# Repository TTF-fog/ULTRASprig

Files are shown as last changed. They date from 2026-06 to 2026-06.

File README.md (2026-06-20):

# the ULTRASprig

an updated version of the [Sprig](https://github.com/hackclub/sprig/), made to be ultra-modular and expansible!

# Why?
the current model of the sprig is a bit... outdated. It still runs on the RP2040, has only 4 (broken out) gpios and just 2Mb of flash. The ULTRASprig has 7 usable GPIOs, and a completely new expansion system that allows for up to 16MB of additional flash, + PSRAM. it also uses I2C "modules" to give even more  interfaces

## Notes:
- KiCad will throw a DRC error for the placement of the mounting headers (courtyard overlap with display), but this can be ignored safely 

# Setup
## RP2354B
- get the larger packages (the BQ, RP2354, and the TP) pre-assembled
- use a stencil to solder the smaller passives
- solder male headers into the broken out pins
## Mainboard
- Solder all components except the pinsockets
- while soldering the pinsockets, make sure to have 1mm of clearance between the tips and the SPI display
- insert the SD Card into the SPI Display
- for the battery headers, one battery header will be connected to the + and - of the battery, and the other should be connected to the battery pins of the coreboard
## Case
- the case must be printed in two parts, the front and the back
- there are 4 mounting holes in the case, which must be connected using screws to those mounting holes on the mainboard
- after that, place the backplate, ensuring that the battery pins line up with the battery hoels
# Usage
- build the firmware and flash it on the sprig

# Sub(Links)
- [Zine](Sprig_Zine.pdf)
- Mainboard
    - [Mainboard BoM](BOM.csv)
    - [Gerbers - Mainboard](gerbers.zip)
    - [Mainboard Design](Mainboard/)
- Core Board
    - [Core BoM](core_board/RP2354B/BOM.csv)
    - [Coreboard Design Files](core_board/RP2354B/)
- Expansions
    - IO Expander   
        - [Design](Expansions/IOExpander/)
        - [Gerbers](Expansions/IOExpander/Gerbers.zip)
        - [BoM](Expansions/IOExpander/BOM.csv)
    - Flash Breakout   
        - [Design](Expansions/FlashBreakout/)
        - [Gerbers](Expansions/FlashBreakout/gerbers.zip)
        - [BoM](Expansions/FlashBreakout/BOM.csv)
    - IMU Breakout   
        - [Design](Expansions/IMUBreakout/)
        - [Gerbers](Expansions/IMUBreakout/Gerbers.zip)
        - [BoM](Expansions/IMUBreakout/BOM.csv)

- [Gerbers - coreboard](core_board/RP2354B/Gerbers.zip)

# Zine
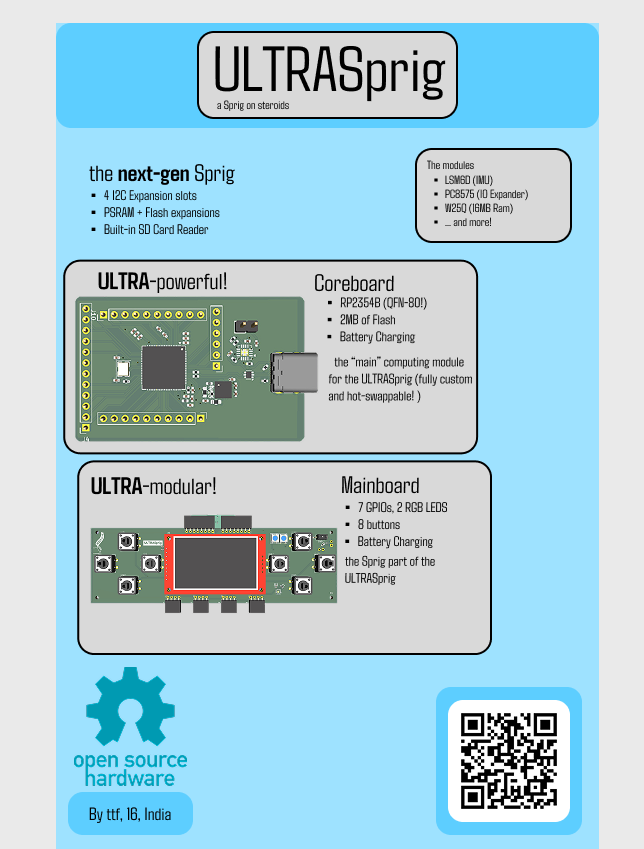
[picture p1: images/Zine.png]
Zine

> check the pdf version too!
# Renders
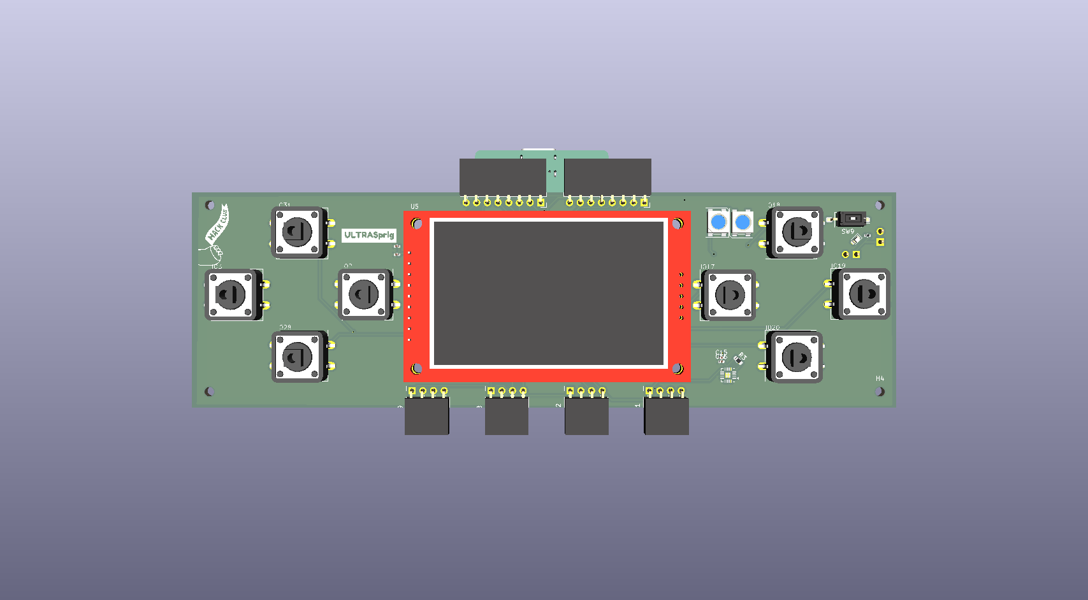
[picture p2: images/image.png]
front view

> front view

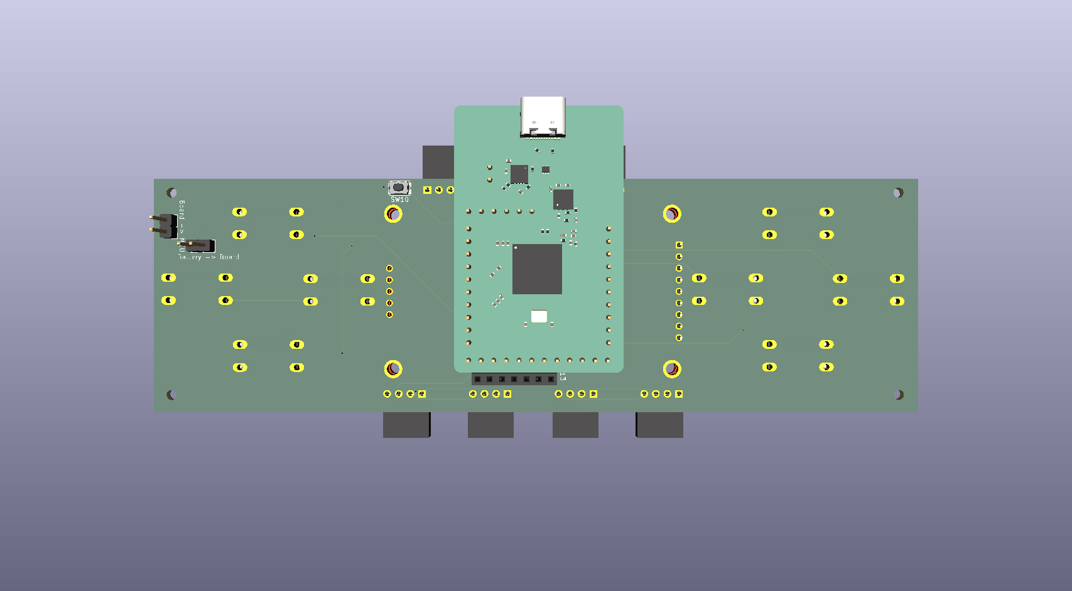
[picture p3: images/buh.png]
back view w/ board and battery headers

> back view w/ board and battery headers

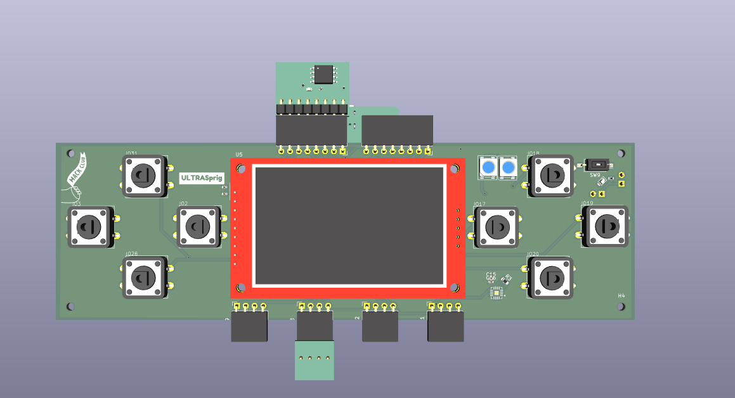
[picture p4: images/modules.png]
main board with modules

> front view, main board with modules

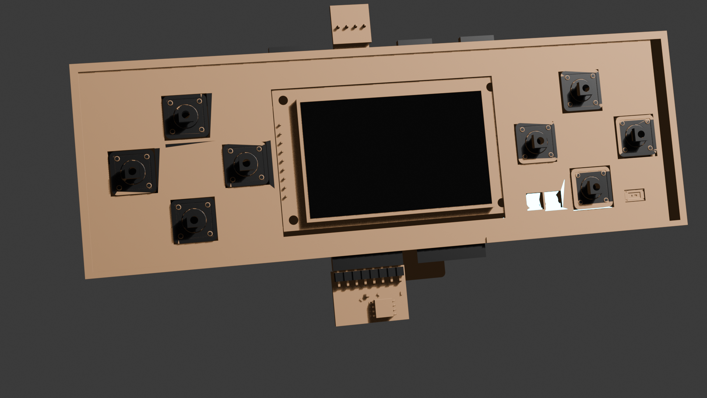
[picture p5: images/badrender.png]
horrible blender render

> a very rushed blender render rhyme

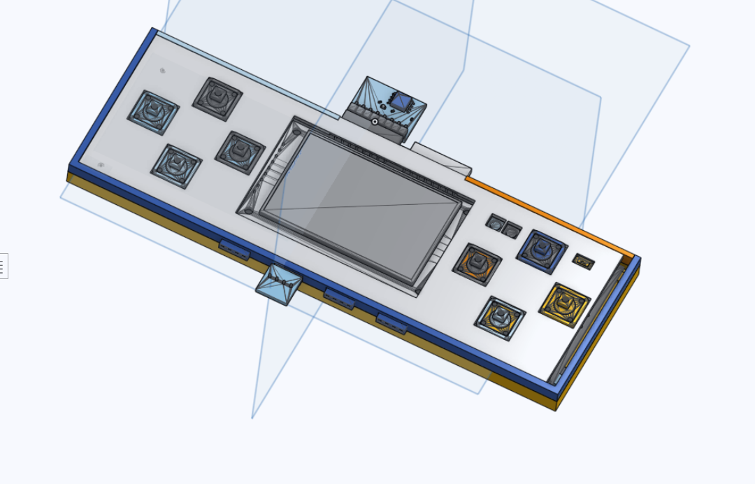
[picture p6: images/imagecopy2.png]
CAD

> case for the ULTRASprig

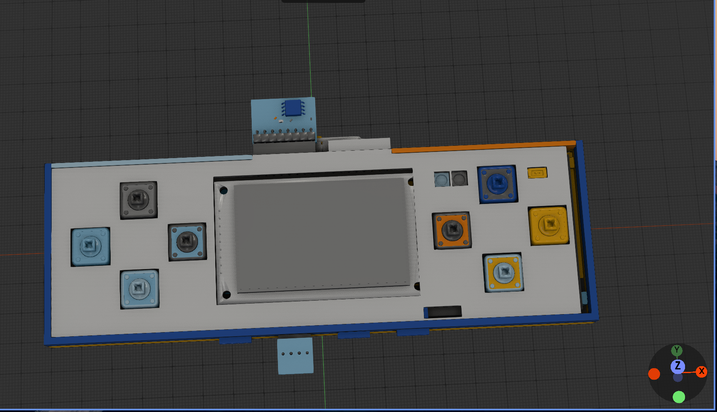
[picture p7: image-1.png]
the 13th reason

> textured preview of CAD
# Routing

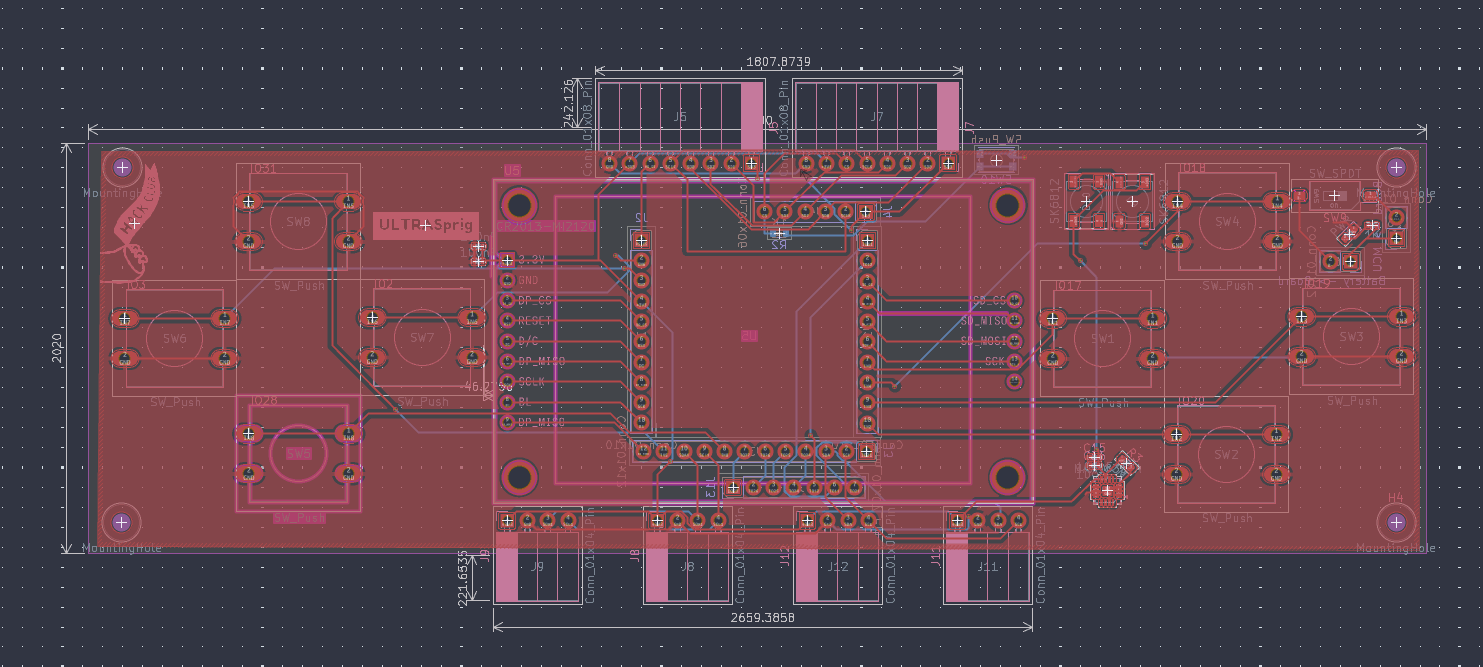
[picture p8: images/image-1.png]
routed mainboard

> routed mainboard

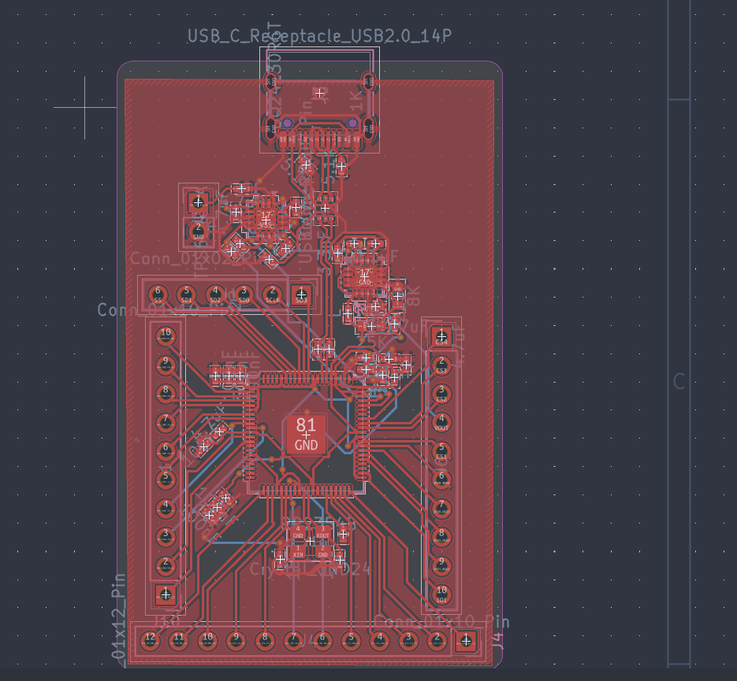
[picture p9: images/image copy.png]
routed coreboard

> routed coreboard

# Schematics
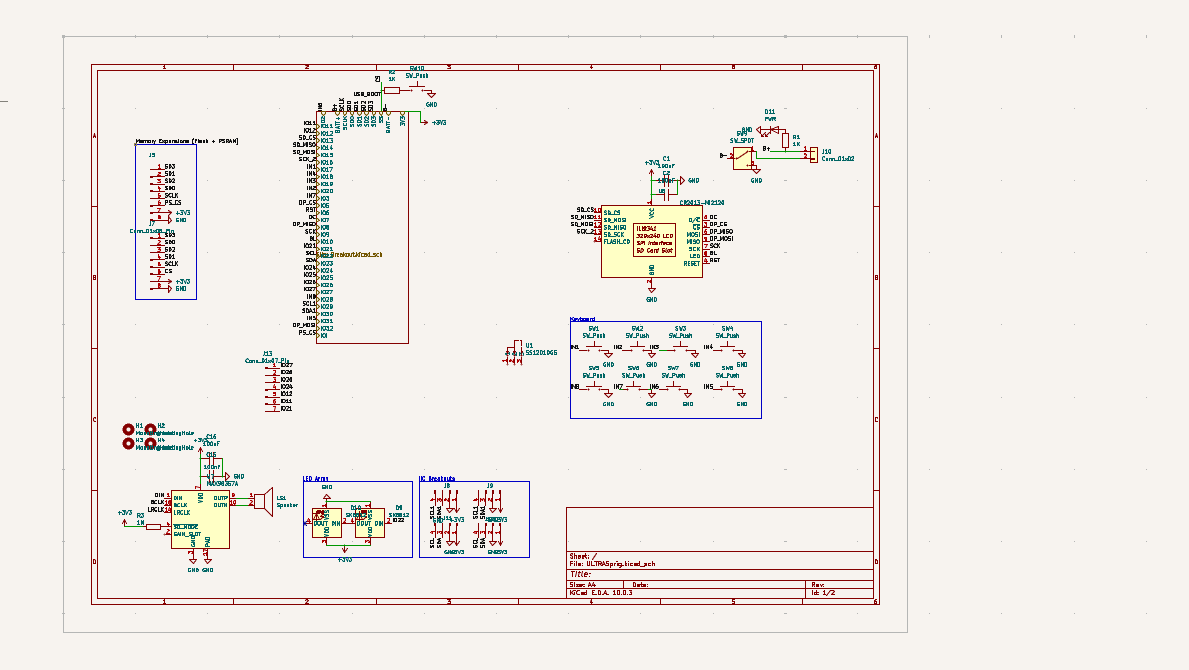
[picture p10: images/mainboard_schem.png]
mainboard schematic

> mainboard schematic

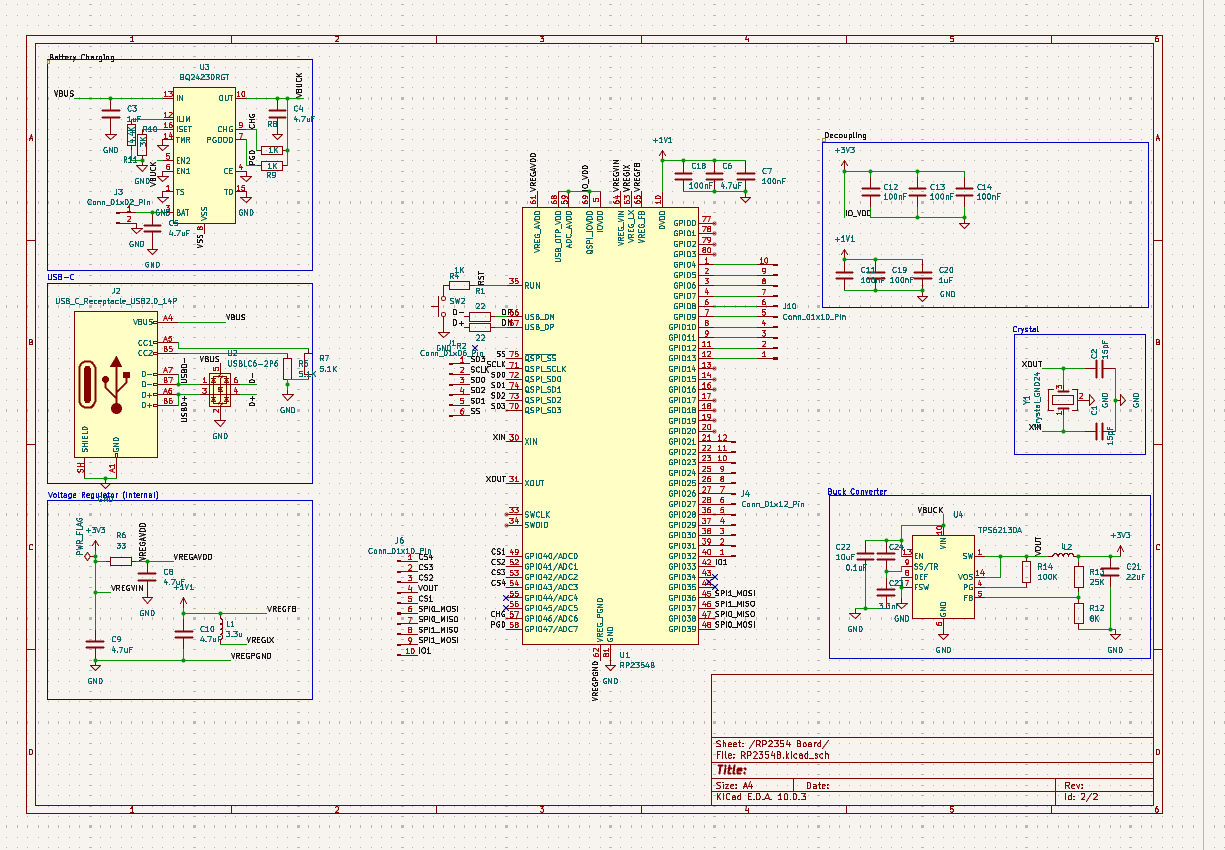
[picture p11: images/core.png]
core schematic

> coreboard schematic

> note: some of the cad model pictures are outdated, double-check the source file

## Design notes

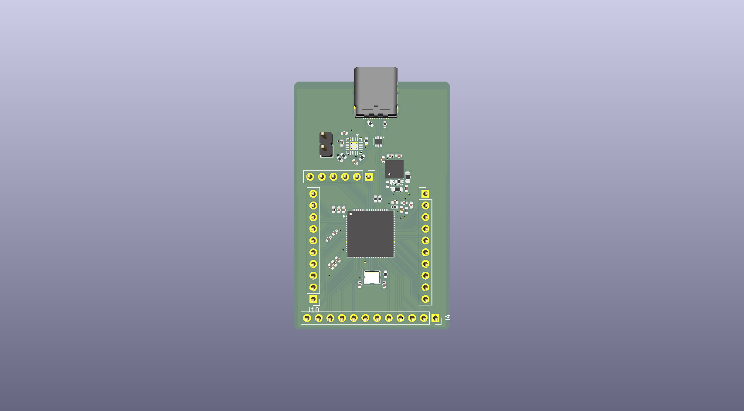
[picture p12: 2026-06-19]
core_board/RP2354B/buh.png

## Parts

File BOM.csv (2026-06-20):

Comment | Designator | Footprint | LCSC | Quantity | URL | Unit Price | Price
100nF | C1,C15,C16,C2 | C_0402_1005Metric | C1525 | 4 | https://www.lcsc.com/product-detail/C1525.html | 0.0031 | 0.31
1K | R1 | R_0402_1005Metric | C11702 | 1 | https://www.lcsc.com/product-detail/C11702.html | 0.0011 | 0.011
1K | R2 | R_0603_1608Metric | C21190 | 1 | https://www.lcsc.com/product-detail/C21190.html | 0.0017 | 0.017
1M | R3 | R_0603_1608Metric | C22935 | 1 | https://www.lcsc.com/product-detail/C22935.html | 0.0018 | 0.18
Conn_01x02 | J10,J6,J14 | PinHeader_1x02_P2.54mm_Vertical | C492401 | 3 | https://www.lcsc.com/product-detail/C492401.html | 0.0161 | 0.95
Conn_01x04_Pin | J11,J12,J8,J9 | PinSocket_1x04_P2.54mm_Horizontal | C2718488 | 4 | https://www.lcsc.com/product-detail/C2718488.html | 0.0786 | 0.79
Conn_01x06 | J4 | PinSocket_1x06_P2.54mm_Vertical | C7499363 | 1 | https://www.lcsc.com/product-detail/C7499363.html | 0.1286 | 0.64
Conn_01x07_Pin | J13 | PinSocket_1x07_P2.54mm_Vertical | C5371993 | 1 | https://www.lcsc.com/product-detail/C5371993.html | 0.0963 | 0.48
Conn_01x08_Pin | J5,J7 | PinSocket_1x08_P2.54mm_Horizontal | C7499328 | 2 | https://www.lcsc.com/product-detail/C7499328.html | 0.1351 | 0.68
Conn_01x10 | J1,J2 | PinSocket_1x10_P2.54mm_Vertical | C2925557 | 2 | https://www.lcsc.com/product-detail/C2925557.html | 0.1279 | 0.64
Conn_01x12 | J3 | PinSocket_1x12_P2.54mm_Vertical | C492401 | 1 | https://www.lcsc.com/product-detail/C492401.html | 0.0161 | 0.81
MAX98357A | U7 | TQFN-16-1EP_3x3mm_P0.5mm_EP1.23x1.23mm | C910544 | 1 | https://www.lcsc.com/product-detail/C910544.html | 1.3362 | 1.34
PWR | D11 | LED_0603_1608Metric | C2286 | 1 | https://www.lcsc.com/product-detail/C2286.html | 0.0073 | 0.73
SK6812 | D10,D9 | LED_SK6812_PLCC4_5.0x5.0mm_P3.2mm | C5378734 | 2 | https://www.lcsc.com/product-detail/C5378734.html | 0.1656 | 0.83
SW_Push | SW1,SW10,SW2,SW3,SW4,SW5,SW6,SW7,SW8 | SW_PUSH-12mm | C963201 | 9 | https://www.lcsc.com/product-detail/C963201.html | 0.216 | 1.08
SW_SPDT | SW9 | SW_SPST_B3S-1100 | C7421519 | 1 | https://www.lcsc.com/product-detail/C7421519.html | 0.444 | 0.44
CR2013-MI2120 | U5 | CR2013-MI2120 | N/A | 1 | https://robu.in/product/2-8-inch-lcm-tft-color-screen-ili9341v-with-spi-serial-port/ | 9.4 | 9.41
PCB Milling | N/A | N/A | N/A |  | https://jlcpcb.com | 7.7 | 7.7
 |  |  |  |  |  | 19.8755 | 27.038

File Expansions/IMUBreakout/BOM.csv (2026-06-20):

Comment | Designator | Footprint | LCSC | Quantity | Link | Unit Price | Total Price
100nF | C1 | C_0402_1005Metric | C1525 | 1 | https://www.lcsc.com/product-detail/C1525.html | 0.0031 | 0.31
1K | R1,R2 | R_0402_1005Metric | C11702 | 2 | https://www.lcsc.com/product-detail/C11702.html | 0.0011 | 0.11
Conn_01x04_Socket | J1 | PinHeader_1x04_P2.54mm_Horizontal | C194925 | 1 | https://www.lcsc.com/product-detail/C194925.html | 0.1205 | 0.6
LED | D1 | LED_0603_1608Metric | C2286 | 1 | https://www.lcsc.com/product-detail/C2286.html | 0.0073 | 0.73
LSM6DS3 | U1 | LGA-14_3x2.5mm_P0.5mm_LayoutBorder3x4y | C967633 | 1 | https://www.lcsc.com/product-detail/C967633.html | 1.576 | 1.58PCB
PCB Milling | N/A | N/A | N/A | 1 | https://jlcpcb.com | 2.2 | 2.2
 |  |  |  |  |  | 3.908 | 5.53

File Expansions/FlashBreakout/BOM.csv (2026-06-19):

Comment | Designator | Footprint | LCSC | Quantity | Link | Per Unit | Total
0 | R1 | R_0402_1005Metric | C17168 | 1 | https://lcsc.com/product-detail/C17168.html | 0.0011 | 0.11
100nF | C1 | C_0402_1005Metric | C1525 | 1 | https://lcsc.com/product-detail/C1525.html | 0.0031 | 0.31
1K | R2 | R_0402_1005Metric | C11702 | 1 | https://lcsc.com/product-detail/C11702.html | 0.0011 | 0.11
Conn_01x08_Pin | J1 | PinHeader_1x08_P2.54mm_Horizontal | C42431840 | 1 | https://lcsc.com/product-detail/C42431840.html | 0.1002 | 0.5
LED | D1 | LED_0603_1608Metric | C2286 | 1 | https://lcsc.com/product-detail/C2286.html | 0.0073 | 0.73
W25Q128JVS | U2 | SOIC-8_5.3x5.3mm_P1.27mm | C97521 | 1 | https://lcsc.com/product-detail/C97521.html | 2.4553 | 2.46
PCB | N/A | N/A | N/A | 1 | https://jlcpcb.com | 2.1 | 2.1
 |  |  |  |  |  | 4.6681 | 6.32

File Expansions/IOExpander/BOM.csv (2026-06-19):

Comment | Designator | Footprint | LCSC | Quantity | Link | Unit Price | Total Price
100nF | C1,C2 | C_0603_1608Metric | C14663 | 2 | https://www.lcsc.com/product-detail/C14663.html | 0.0172 | 1.72
Conn_01x04 | J1 | PinHeader_1x04_P2.54mm_Horizontal | C52016392 | 1 | https://www.lcsc.com/product-detail/C52016392.html | 0.0283 | 0.57
PCF8574AP | U1 | DIP-16_W7.62mm | C398072 | 1 | https://www.lcsc.com/product-detail/C398072.html | 0.79 | 0.79
Conn_01x08 | J2 | PinHeader_1x08_P2.54mm_Horizontal | C20607071 | 1 | https://www.lcsc.com/product-detail/C20607071.html | 0.0958 | 0.48
PCB Milling | n/a | n/a | n/a | 1 | https://jlcpcb.com | 2.2 | 2.2
 |  |  |  |  |  | 3.1313 | 5.76

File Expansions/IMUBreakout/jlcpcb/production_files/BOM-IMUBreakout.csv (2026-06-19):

Comment | Designator | Footprint | LCSC | Quantity
100nF | C1 | C_0402_1005Metric | C1525 | 1
1K | R1,R2 | R_0402_1005Metric | C11702 | 2
Conn_01x04_Socket | J1 | PinHeader_1x04_P2.54mm_Horizontal | C194925 | 1
LED | D1 | LED_0603_1608Metric | C2286 | 1
LSM6DS3 | U1 | LGA-14_3x2.5mm_P0.5mm_LayoutBorder3x4y | C967633 | 1

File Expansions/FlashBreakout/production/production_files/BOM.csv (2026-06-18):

Comment | Designator | Footprint | LCSC | Quantity
0 | R1 | R_0402_1005Metric | C17168 | 1
100nF | C1 | C_0402_1005Metric | C1525 | 1
1K | R2 | R_0402_1005Metric | C11702 | 1
Conn_01x08_Pin | J1 | PinHeader_1x08_P2.54mm_Horizontal | C42431840 | 1
LED | D1 | LED_0603_1608Metric | C2286 | 1
W25Q128JVS | U2 | SOIC-8_5.3x5.3mm_P1.27mm | C97521 | 1

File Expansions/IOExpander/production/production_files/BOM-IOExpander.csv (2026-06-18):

Comment | Designator | Footprint | LCSC | Quantity
100nF | C1,C2 | C_0603_1608Metric | C14663 | 2
Conn_01x04 | J1 | PinHeader_1x04_P2.54mm_Horizontal | C52016392 | 1
PCF8574AP | U1 | DIP-16_W7.62mm | C398072 | 1
Conn_01x08 | J2 | PinHeader_1x08_P2.54mm_Horizontal | C20607071 | 1

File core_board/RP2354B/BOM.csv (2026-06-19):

Comment | Designator | Footprint | LCSC | Quantity | Link | Unit Price | Total Price
0.1uF | C24 | C_0402_1005Metric | C15195 | 1 | https://www.lcsc.com/product-detail/C15195.html | 0.0025 | 0.025
100K | R14 | R_0402_1005Metric | C25741 | 1 | https://www.lcsc.com/product-detail/C25741.html | $ 0.0011 | 0.11
100nF | C11,C12,C13,C14,C18,C19,C7 | C_0402_1005Metric | C1525 | 7 | https://www.lcsc.com/product-detail/C1525.html | 0.0031 | 0.031
10uF | C22 | C_0402_1005Metric | C15525 | 1 | https://www.lcsc.com/product-detail/C15525.html | 0.0199 | 1.99
15pF | C1,C2 | C_0402_1005Metric | C1548 | 2 | https://www.lcsc.com/product-detail/C1548.html | 0.0022 | 0.22
1K | R4,R8,R9 | R_0402_1005Metric | C11702 | 3 | https://www.lcsc.com/product-detail/C11702.html | 0.0011 | 0.11
1uF | C20,C3 | C_0402_1005Metric | C52923 | 2 | https://www.lcsc.com/product-detail/C52923.html | 0.0143 | 0.72
22 | R1,R2 | R_0402_1005Metric | C25092 | 2 | https://www.lcsc.com/product-detail/C25092.html | 0.0009 | 0.09
22uF | C21 | C_0402_1005Metric | C105226 | 1 | https://www.lcsc.com/product-detail/C105226.html | 0.075 | 0.38
25K | R13 | R_0603_1608Metric | C2828637 | 1 | https://www.lcsc.com/product-detail/C2828637.html | 0.035 | 0.7
3.3nF | C23 | C_0402_1005Metric | C26404 | 1 | https://www.lcsc.com/product-detail/C26404.html | 0.006 | 0.12
3.3u | L1 | L_0402_1005Metric | C48946153 | 1 | https://www.lcsc.com/product-detail/C48946153.html | 0.0425 | 0.43
33 | R6 | R_0402_1005Metric | C25105 | 1 | https://www.lcsc.com/product-detail/C25105.html | 0.001 | 0.1
3K | R10 | R_0402_1005Metric | C25559 | 1 | https://www.lcsc.com/product-detail/C25559.html | 0.0007 | 0.07
4.4K | R11 | R_0402_1005Metric | C2088643 | 1 | https://www.lcsc.com/product-detail/C2088643.html | 0.3144 | 0.31
4.7uF | C10,C4,C5,C6,C8,C9 | C_0402_1005Metric | C23733 | 6 | https://www.lcsc.com/product-detail/C23733.html | 0.0192 | 0.96
5.1K | R5,R7 | R_0402_1005Metric | C25905 | 2 | https://www.lcsc.com/product-detail/C25905.html | 0.0009 | 0.09
8K | R12 | R_0603_1608Metric | C2924154 | 1 | https://www.lcsc.com/product-detail/C2924154.html | 0.0142 | 0.71
BQ24230RGT | U3 | VQFN-16-1EP_3x3mm_P0.5mm_EP1.68x1.68mm_ThermalVias | C138361 | 1 | https://www.lcsc.com/product-detail/C138361.html | 2.2652 | 2.27
Conn_01x02_Pin | J3 | PinHeader_1x02_P2.54mm_Vertical | C52016390 | 1 | https://www.lcsc.com/product-detail/C52016390.html | 0.013 | 0.65
Conn_01x06_Pin | J1 | PinHeader_1x06_P2.54mm_Vertical | C293309 | 1 | https://www.lcsc.com/product-detail/C293309.html | 1.1299 | 1.13
Conn_01x10_Pin | J10,J6 | PinHeader_1x10_P2.54mm_Vertical | C2925557 | 2 | https://www.lcsc.com/product-detail/C2925557.html | 0.1279 | 0.64
Conn_01x12_Pin | J4 | PinSocket_1x12_P2.54mm_Vertical | C293309 | 1 | https://www.lcsc.com/product-detail/C293309.html | 1.1299 | 1.13
Crystal_GND24 | Y1 | Crystal_SMD_3225-4Pin_3.2x2.5mm | C20625731 | 1 | https://www.lcsc.com/product-detail/C20625731.html | 0.2956 | 1.48
L | L2 | L_0402_1005Metric | C49067 | 1 | https://www.lcsc.com/product-detail/C383389.html | 0.0564 | 0.56
RP2354B | U1 | QFN-80-1EP_10x10mm_P0.4mm_EP3.4x3.4mm | C39843328 | 1 | https://www.lcsc.com/product-detail/C39843328.html | 1.5739 | 1.57
TPS62130A | U4 | VQFN-16-1EP_3x3mm_P0.5mm_EP1.68x1.68mm_ThermalVias | C2070623 | 1 | https://www.lcsc.com/product-detail/C2070623.html | 1.3236 | 1.32
USBLC6-2P6 | U2 | SOT-666 | C53059594 | 1 | https://www.lcsc.com/product-detail/C53059594.html | 0.08 | 0.4
USB_C_Receptacle_USB2.0_14P | J2 | USB_C_Receptacle_HRO_TYPE-C-31-M-12 | C165948 | 1 | https://www.lcsc.com/product-detail/C165948.html | 0.1857 | 0.93
PCB Milling | N/A | N/A | N/A | 1 | https://jlcpcb.com | 5.31 | 5.31
 |  |  |  |  |  | 14.044 | 24.556

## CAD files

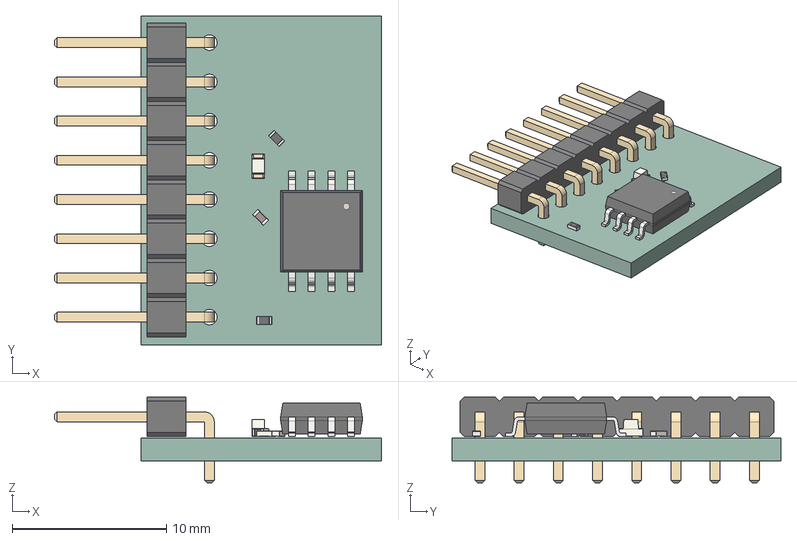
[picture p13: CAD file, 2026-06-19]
Expansions/FlashBreakout/flash.step
21.2 x 21.3 x 5.54 mm
R_0402_1005Metric x 2
PinHeader_1x08_P254mm_Horizontal
SOIC-8_5.3x5.3mm_P1.27mm
C_0402_1005Metric
LED_0603_1608Metric
Flash_PCB

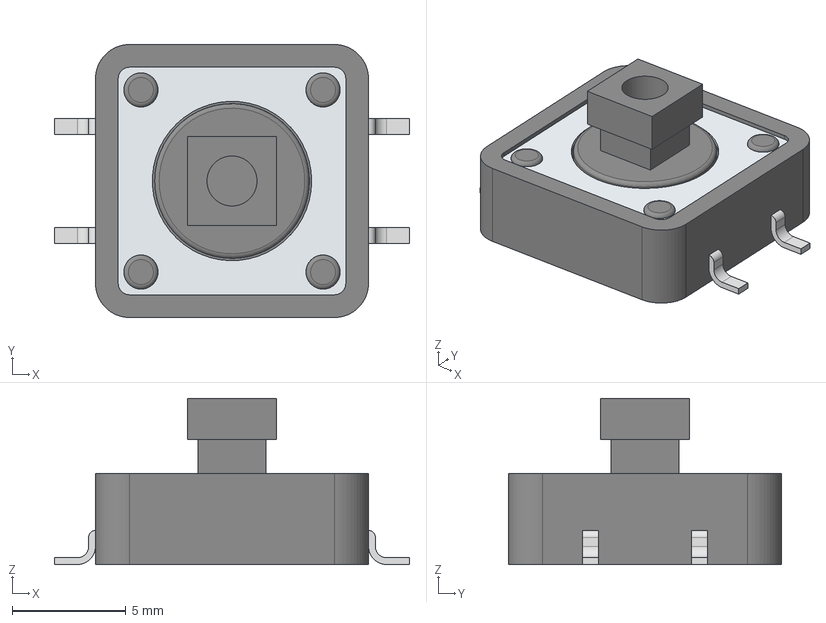
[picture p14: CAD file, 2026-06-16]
models/bug-pushbutton-12x12mm-1.snapshot.2/Big_pushbutton.stp
15.6 x 12.0 x 7.30 mm
Button_body
Button_cover
Button_pin x 4

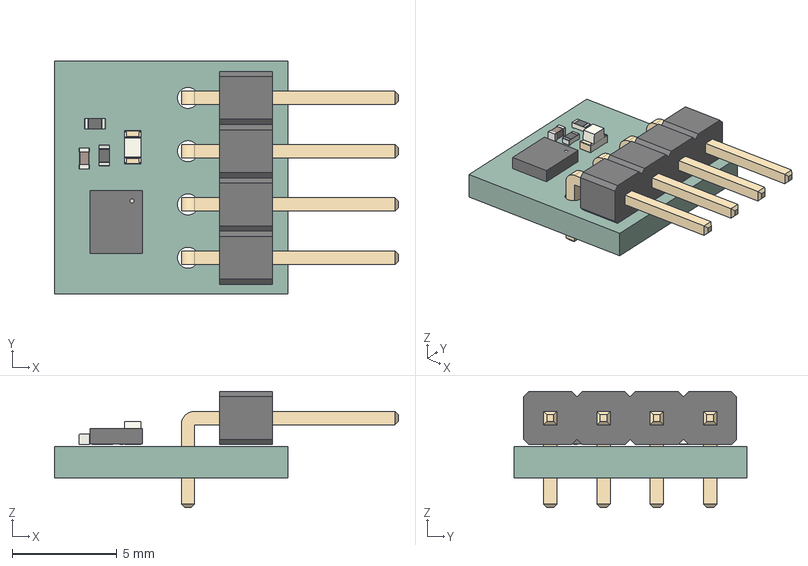
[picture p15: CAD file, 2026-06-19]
models/imu.step
16.4 x 11.1 x 5.54 mm
R_0402_1005Metric x 2
C_0402_1005Metric
PinHeader_1x04_P254mm_Horizontal
LED_0603_1608Metric
LGA_14_3x25mm_P05mm_LayoutBorder3x4y
IMUBreakout_PCB

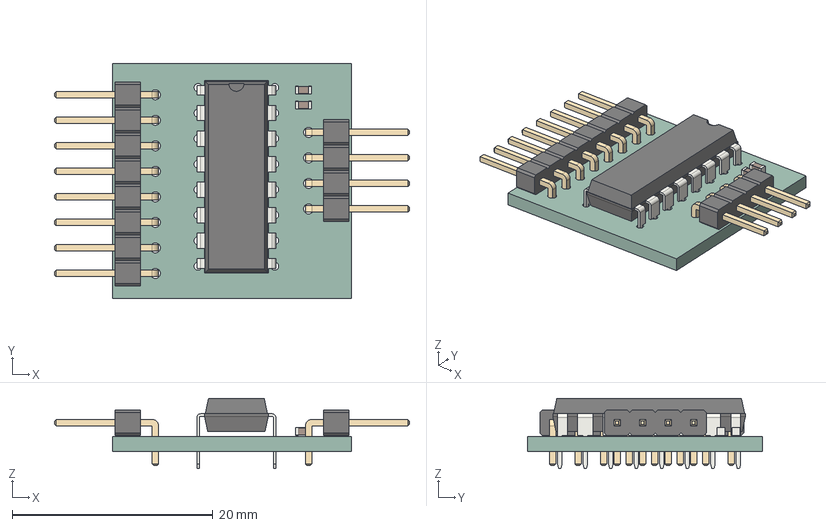
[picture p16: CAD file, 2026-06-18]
models/IOExpander.step
35.3 x 23.4 x 6.98 mm
PinHeader_1x08_P254mm_Horizontal
DIP-16_W7.62mm
C_0603_1608Metric x 2
PinHeader_1x04_P254mm_Horizontal
IOExpander_PCB

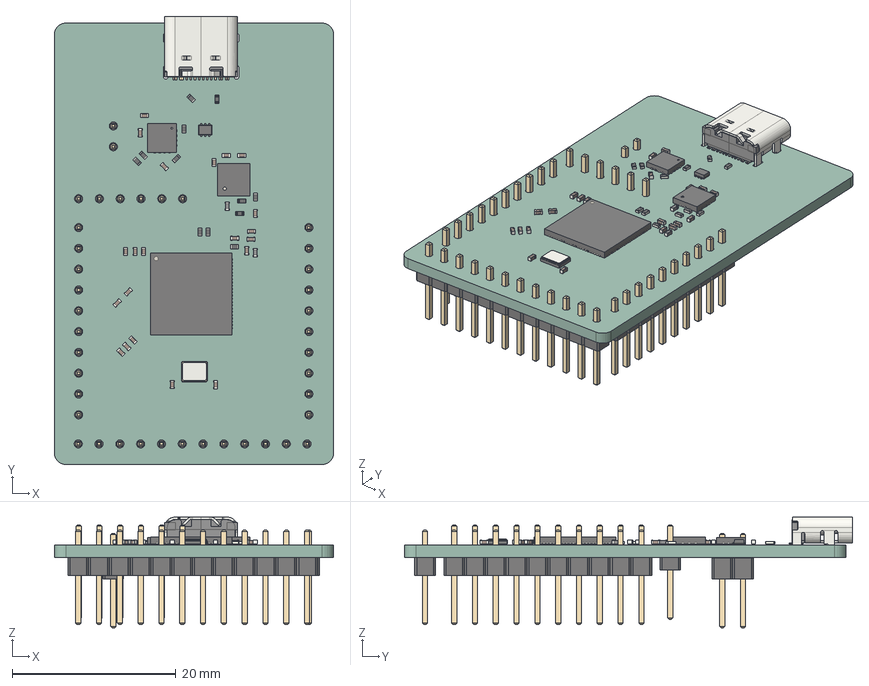
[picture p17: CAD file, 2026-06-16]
models/RP.step
34.1 x 54.7 x 13.5 mm
Crystal_SMD_3225-4Pin_3.2x2.5mm
C_0402_1005Metric x 21
ArtInChip_QFN-88-1EP_10x10mm_P0.4mm_EP6.74x6.74mm
PinHeader_1x10_P254mm_Vertical x 2
R_0402_1005Metric x 12
WQFN_16_1EP_3x3mm_P05mm_EP16x16mm
PinHeader_1x12_P254mm_Vertical
VQFN-12-1EP_4x4mm_P0.8mm_EP2.1x2.1mm
SOT_666
L_0402_1005Metric x 2
USB_C_Receptacle_16P_TopMnt_Horizontal_GCT_USB4105-xx-A
PinHeader_1x06_P254mm_Vertical
PinHeader_1x02_P254mm_Vertical
RP2354B_PCB

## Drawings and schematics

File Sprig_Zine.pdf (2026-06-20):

# the next-gen Sprig

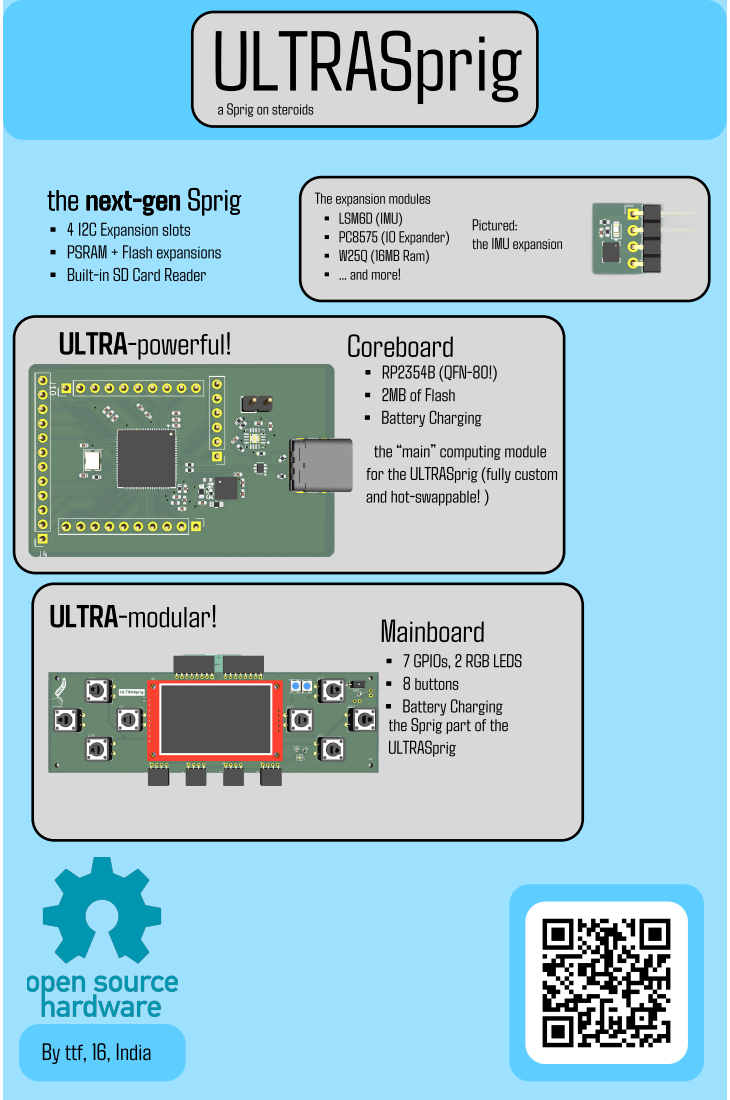
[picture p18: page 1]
ULTRA-powerful!; Coreboard; RP2354B (QFN-80!); 2MB of Flash; Battery Charging; ULTRA-modular!; Mainboard

ULTRASprig a Sprig on steroids

The expansion modules
LSM6D (IMU)
PC8575 (IO Expander)
W25Q (16MB Ram)
... and more!

4 I2C Expansion slots
PSRAM + Flash expansions
Built-in SD Card Reader

Pictured:
the IMU expansion

the “main” computing module
for the ULTRASprig (fully custom
and hot-swappable! )

7 GPIOs, 2 RGB LEDS
8 buttons
Battery Charging
the Sprig part of the
ULTRASprig

By ttf, 16, India

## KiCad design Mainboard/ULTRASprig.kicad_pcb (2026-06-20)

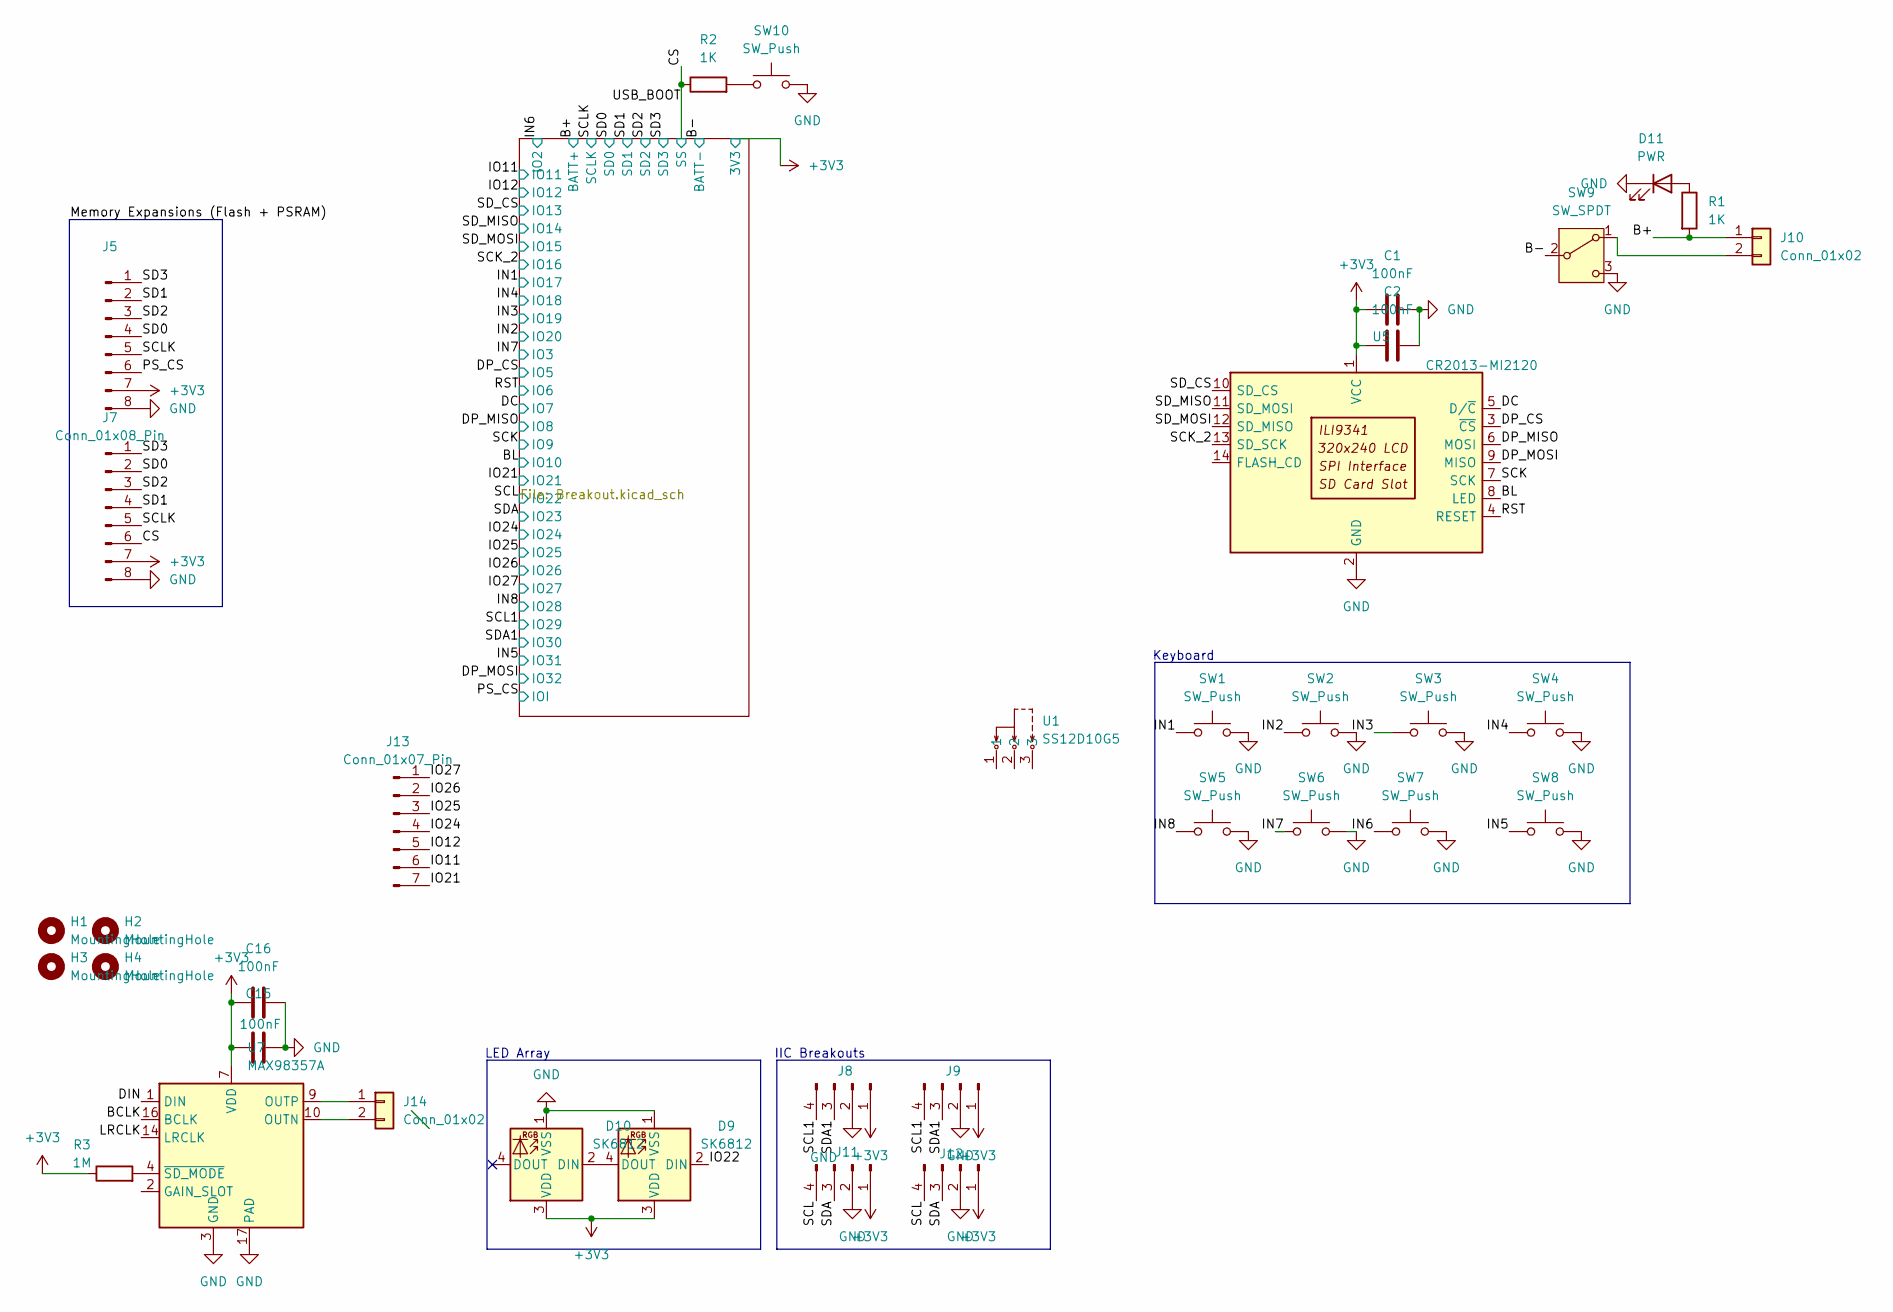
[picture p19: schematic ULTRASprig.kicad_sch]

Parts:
C1, C2, C15, C16: 100nF; C_0402_1005Metric
D9, D10: SK6812; LED_SK6812_PLCC4_5.0x5.0mm_P3.2mm
D11: PWR; LED_0603_1608Metric
H1, H2, H3, H4: MountingHole; MountingHole_2.2mm_M2
J5, J7: Conn_01x08_Pin; PinSocket_1x08_P2.54mm_Horizontal
J8, J9, J11, J12: Conn_01x04_Pin; PinSocket_1x04_P2.54mm_Horizontal
J10, J14: Conn_01x02; PinHeader_1x02_P2.54mm_Vertical
J13: Conn_01x07_Pin; PinSocket_1x07_P2.54mm_Vertical
R1: 1K; R_0402_1005Metric
R2: 1K; R_0603_1608Metric
R3: 1M; R_0603_1608Metric
SW1, SW2, SW3, SW4, SW5, SW6, SW7, SW8: SW_Push; SW_PUSH-12mm
SW9: SW_SPDT; SW_SPST_B3S-1100
SW10: SW_Push; SW_Push_1P1T_NO_CK_KMR2
U1: SS12D10G5; SW-TH_SHOU-HAN_SS12D10G4; MPN SS12D10G5; LCSC Part C7431054
U5: CR2013-MI2120
U7: MAX98357A; TQFN-16-1EP_3x3mm_P0.5mm_EP1.23x1.23mm

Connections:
+3V3: C1.1, C2.1, C15.2, C16.2, D9.3 (VDD), D10.3 (VDD), J5.7, J7.7, J8.1, J9.1, J11.1, J12.1, R3.1, U5.1 (VCC), U7.7 (VDD), U7.8 (VDD); also elsewhere on the board
/B+: J10.1, R1.2; also elsewhere on the board
/B-: SW9.2 (B); also elsewhere on the board
/BCLK: U7.16 (BCLK)
/BL: U5.8 (LED); also elsewhere on the board
/CS: J7.6, R2.1; also elsewhere on the board
/DC: U5.5 (D/~C); also elsewhere on the board
/DIN: U7.1 (DIN)
/DP_CS: U5.3 (~CS); also elsewhere on the board
/DP_MISO: U5.6 (MOSI); also elsewhere on the board
/DP_MOSI: U5.9 (MISO); also elsewhere on the board
/IN1: SW1.1; also elsewhere on the board
/IN2: SW2.1; also elsewhere on the board
/IN3: SW3.1; also elsewhere on the board
/IN4: SW4.1; also elsewhere on the board
/IN5: SW8.1; also elsewhere on the board
/IN6: SW7.1; also elsewhere on the board
/IN7: SW6.1; also elsewhere on the board
/IN8: SW5.1; also elsewhere on the board
/IO11: J13.6; also elsewhere on the board
/IO12: J13.5; also elsewhere on the board
/IO21: J13.7; also elsewhere on the board
/IO22: D9.2 (DIN)
/IO24: J13.4; also elsewhere on the board
/IO25: J13.3; also elsewhere on the board
/IO26: J13.2; also elsewhere on the board
/IO27: J13.1; also elsewhere on the board
/LRCLK: U7.14 (LRCLK)
/PS_CS: J5.6; also elsewhere on the board
/RST: U5.4 (RESET); also elsewhere on the board
/SCK: U5.7 (SCK); also elsewhere on the board
/SCK_2: U5.13 (SD_SCK); also elsewhere on the board
/SCL: J11.4, J12.4; also elsewhere on the board
/SCL1: J8.4, J9.4; also elsewhere on the board
/SCLK: J5.5, J7.5; also elsewhere on the board
/SD0: J5.4, J7.2; also elsewhere on the board
/SD1: J5.2, J7.4; also elsewhere on the board
/SD2: J5.3, J7.3; also elsewhere on the board
/SD3: J5.1, J7.1; also elsewhere on the board
/SDA: J11.3, J12.3; also elsewhere on the board
/SDA1: J8.3, J9.3; also elsewhere on the board
/SD_CS: U5.10 (SD_CS); also elsewhere on the board
/SD_MISO: U5.11 (SD_MOSI); also elsewhere on the board
/SD_MOSI: U5.12 (SD_MISO); also elsewhere on the board
GND: C1.2, C2.2, C15.1, C16.1, D9.1 (VSS), D10.1 (VSS), D11.1 (K), J5.8, J7.8, J8.2, J9.2, J11.2, J12.2, SW1.2, SW2.2, SW3.2, SW4.2, SW5.2, SW6.2, SW7.2, SW8.2, SW9.3 (C), SW10.2, U5.2 (GND), U7.3 (GND), U7.11 (GND), U7.15 (GND), U7.17 (PAD)
unnamed: D9.4 (DOUT), D10.2 (DIN)
unnamed: D11.2 (A), R1.1
unnamed: J10.2, SW9.1 (A)
unnamed: J14.1, U7.9 (OUTP)
unnamed: J14.2, U7.10 (OUTN)
unnamed: R2.2, SW10.1
unnamed: R3.2, U7.4 (~SD_MODE)

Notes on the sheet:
Keyboard
LED Array
IIC Breakouts

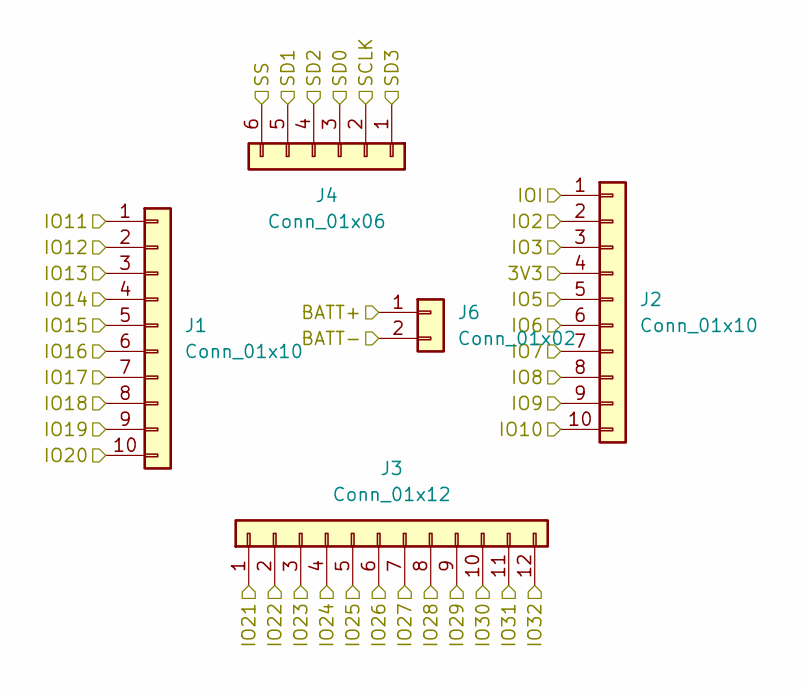
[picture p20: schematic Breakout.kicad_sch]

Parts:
J1, J2: Conn_01x10; PinSocket_1x10_P2.54mm_Vertical
J3: Conn_01x12; PinSocket_1x12_P2.54mm_Vertical
J4: Conn_01x06; PinSocket_1x06_P2.54mm_Vertical
J6: Conn_01x02; PinHeader_1x02_P2.54mm_Vertical

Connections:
+3V3: J2.4; also elsewhere on the board
/B+: J6.1; also elsewhere on the board
/B-: J6.2; also elsewhere on the board
/BL: J2.10; also elsewhere on the board
/CS: J4.6; also elsewhere on the board
/DC: J2.7; also elsewhere on the board
/DP_CS: J2.5; also elsewhere on the board
/DP_MISO: J2.8; also elsewhere on the board
/DP_MOSI: J3.12; also elsewhere on the board
/IN1: J1.7; also elsewhere on the board
/IN2: J1.10; also elsewhere on the board
/IN3: J1.9; also elsewhere on the board
/IN4: J1.8; also elsewhere on the board
/IN5: J3.11; also elsewhere on the board
/IN6: J2.2; also elsewhere on the board
/IN7: J2.3; also elsewhere on the board
/IN8: J3.8; also elsewhere on the board
/IO11: J1.1; also elsewhere on the board
/IO12: J1.2; also elsewhere on the board
/IO21: J3.1; also elsewhere on the board
/IO24: J3.4; also elsewhere on the board
/IO25: J3.5; also elsewhere on the board
/IO26: J3.6; also elsewhere on the board
/IO27: J3.7; also elsewhere on the board
/PS_CS: J2.1; also elsewhere on the board
/RST: J2.6; also elsewhere on the board
/SCK: J2.9; also elsewhere on the board
/SCK_2: J1.6; also elsewhere on the board
/SCL: J3.2; also elsewhere on the board
/SCL1: J3.9; also elsewhere on the board
/SCLK: J4.2; also elsewhere on the board
/SD0: J4.3; also elsewhere on the board
/SD1: J4.5; also elsewhere on the board
/SD2: J4.4; also elsewhere on the board
/SD3: J4.1; also elsewhere on the board
/SDA: J3.3; also elsewhere on the board
/SDA1: J3.10; also elsewhere on the board
/SD_CS: J1.3; also elsewhere on the board
/SD_MISO: J1.4; also elsewhere on the board
/SD_MOSI: J1.5; also elsewhere on the board

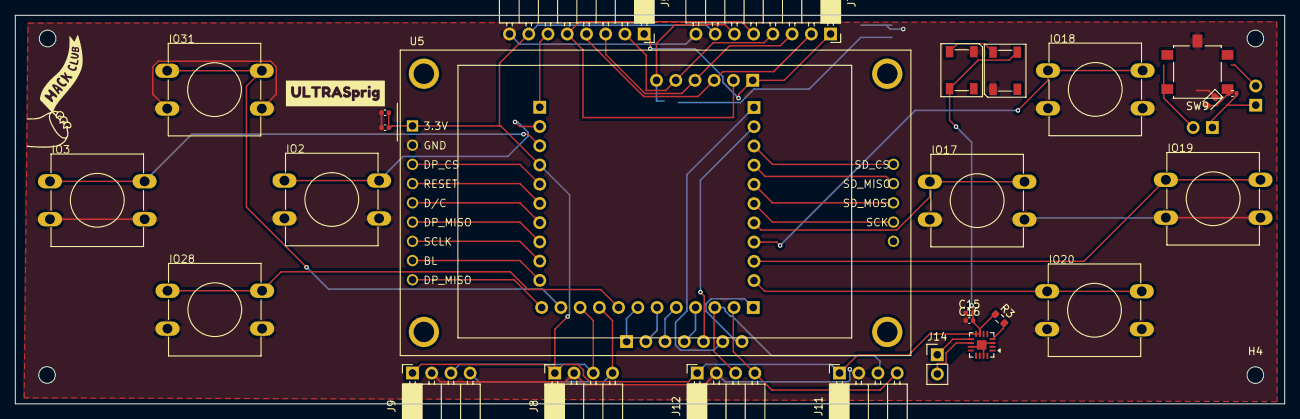
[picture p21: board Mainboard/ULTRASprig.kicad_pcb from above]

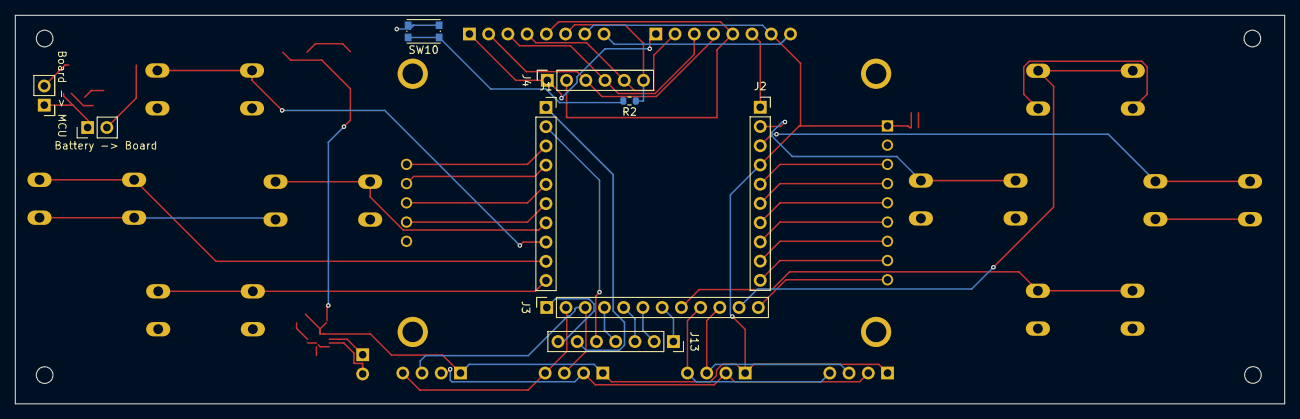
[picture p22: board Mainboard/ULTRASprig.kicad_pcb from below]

Board: 2 copper layers, 167.6 x 51.3 mm, 41 parts (9 on the bottom side), 48 nets.

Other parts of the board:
kibuzzard-6A30251C: G***; kibuzzard-6A30251C

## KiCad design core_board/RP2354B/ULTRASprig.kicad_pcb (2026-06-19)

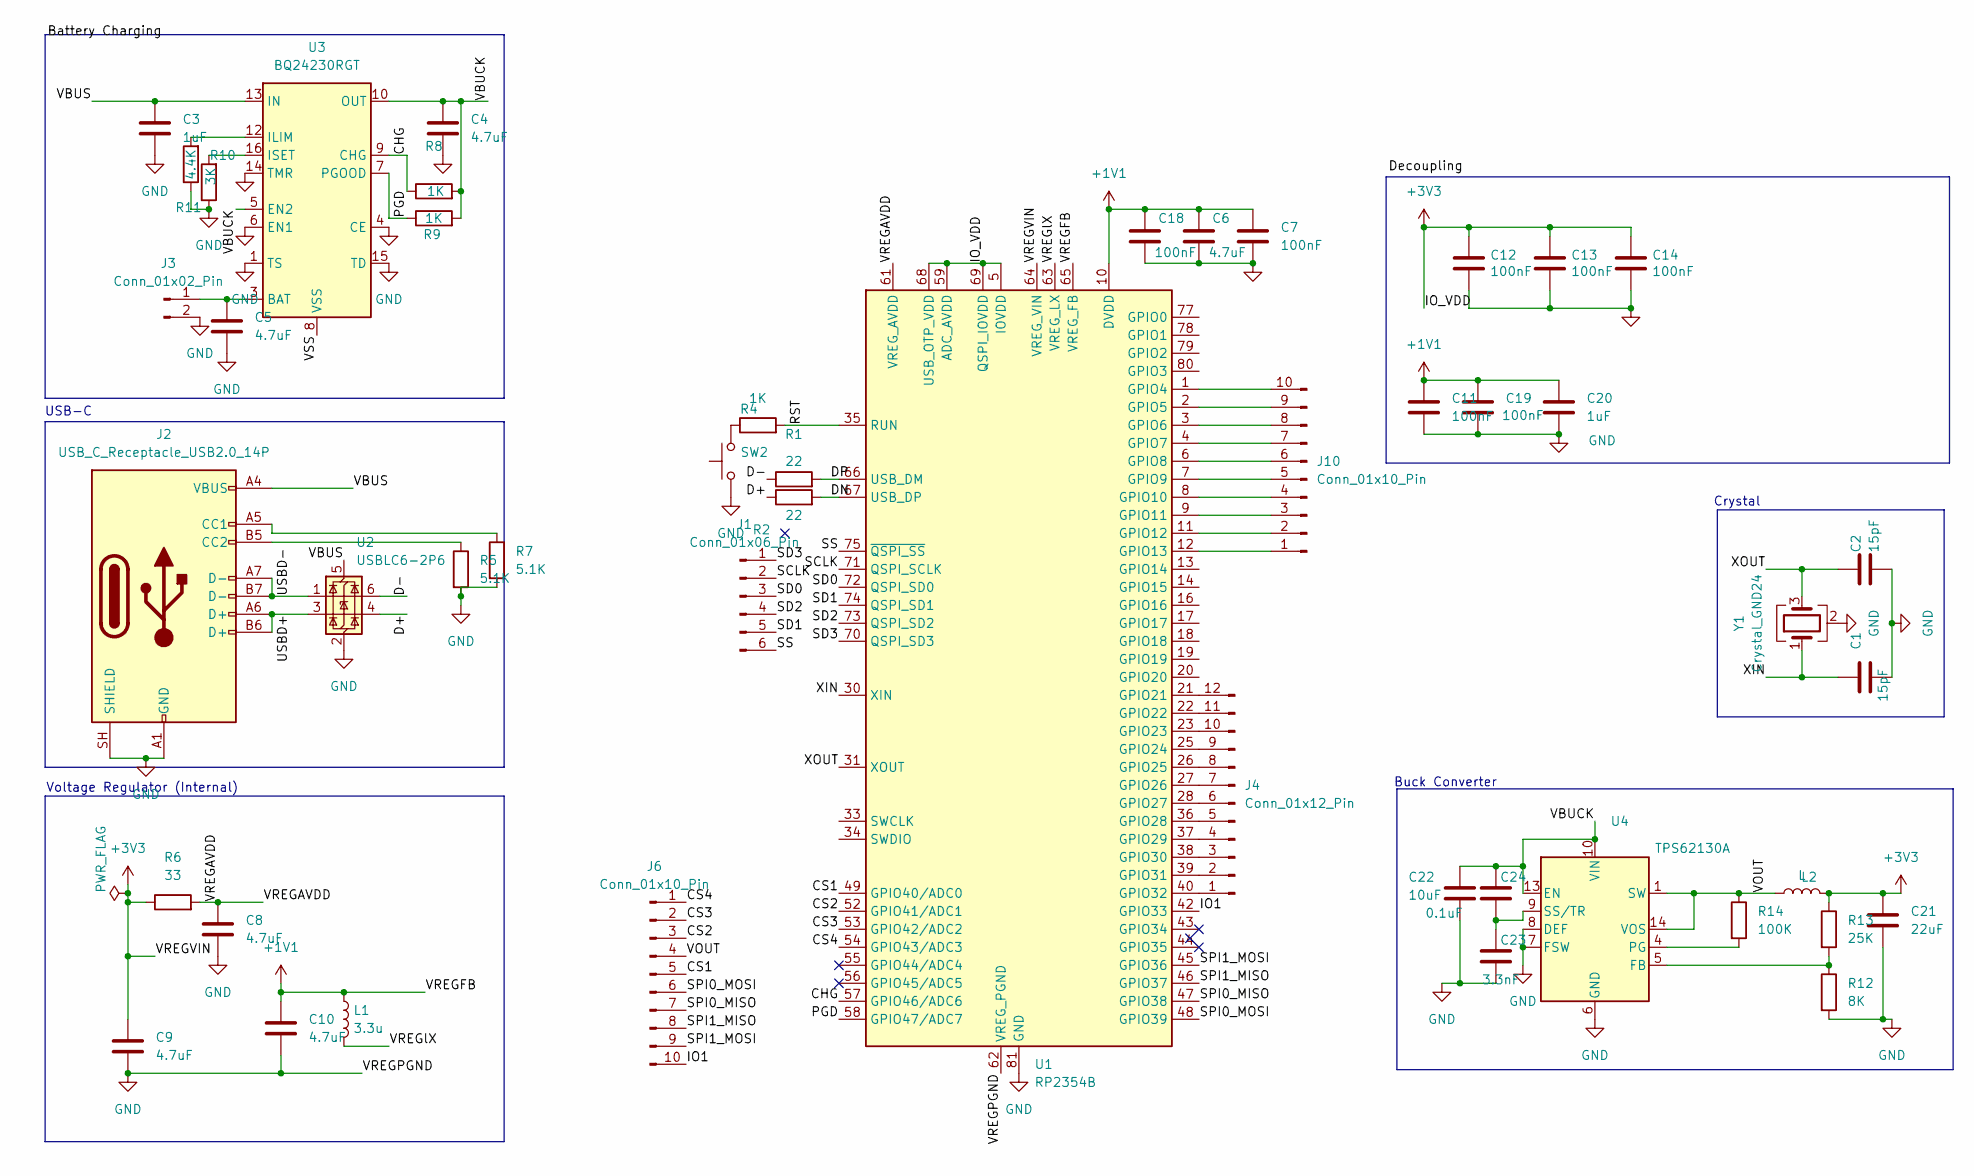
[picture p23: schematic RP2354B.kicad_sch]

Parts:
C1, C2: 15pF; C_0402_1005Metric
C3, C20: 1uF; C_0402_1005Metric
C4, C5, C6, C8, C9, C10: 4.7uF; C_0402_1005Metric
C7, C11, C12, C13, C14, C18, C19: 100nF; C_0402_1005Metric
C21: 22uF; C_0402_1005Metric
C22: 10uF; C_0402_1005Metric
C23: 3.3nF; C_0402_1005Metric
C24: 0.1uF; C_0402_1005Metric
J1: Conn_01x06_Pin; PinHeader_1x06_P2.54mm_Vertical
J2: USB_C_Receptacle_USB2.0_14P; USB_C_Receptacle_HRO_TYPE-C-31-M-12
J3: Conn_01x02_Pin; PinHeader_1x02_P2.54mm_Vertical
J4: Conn_01x12_Pin; PinSocket_1x12_P2.54mm_Vertical
J6, J10: Conn_01x10_Pin; PinHeader_1x10_P2.54mm_Vertical
L1: 3.3u; L_0402_1005Metric
L2: L; L_0402_1005Metric
R1, R2: 22; R_0402_1005Metric
R4, R8, R9: 1K; R_0402_1005Metric
R5, R7: 5.1K; R_0402_1005Metric
R6: 33; R_0402_1005Metric
R10: 3K; R_0402_1005Metric
R11: 4.4K; R_0402_1005Metric
R12: 8K; R_0402_1005Metric
R13: 25K; R_0603_1608Metric
R14: 100K; R_0402_1005Metric
SW2: SW_Push
U1: RP2354B; QFN-80-1EP_10x10mm_P0.4mm_EP3.4x3.4mm
U2: USBLC6-2P6; SOT-666
U3: BQ24230RGT; VQFN-16-1EP_3x3mm_P0.5mm_EP1.68x1.68mm_ThermalVias
U4: TPS62130A; VQFN-16-1EP_3x3mm_P0.5mm_EP1.68x1.68mm_ThermalVias
Y1: Crystal_GND24; Crystal_SMD_3225-4Pin_3.2x2.5mm

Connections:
+1V1: C6.1, C7.1, C10.1, C11.1, C18.1, C19.1, C20.1, L1.1, U1.10 (DVDD), U1.32 (DVDD), U1.51 (DVDD), U1.65 (VREG_FB)
+3V3: C9.1, C12.1, C13.1, C14.1, C21.1, L2.2, R6.1, R13.1, U1.5 (IOVDD), U1.15 (IOVDD), U1.24 (IOVDD), U1.29 (IOVDD), U1.41 (IOVDD), U1.50 (IOVDD), U1.59 (ADC_AVDD), U1.60 (IOVDD), U1.64 (VREG_VIN), U1.68 (USB_OTP_VDD), U1.69 (QSPI_IOVDD), U1.76 (IOVDD)
/RP2354 Board/CHG: R8.1, U1.57 (GPIO46/ADC6), U3.9 (CHG)
/RP2354 Board/CS1: J6.5, U1.49 (GPIO40/ADC0)
/RP2354 Board/CS2: J6.3, U1.52 (GPIO41/ADC1)
/RP2354 Board/CS3: J6.2, U1.53 (GPIO42/ADC2)
/RP2354 Board/CS4: J6.1, U1.54 (GPIO43/ADC3)
/RP2354 Board/D+: R2.1, U2.4 (I/O2)
/RP2354 Board/D-: R1.1, U2.6 (I/O1)
/RP2354 Board/DN: R2.2, U1.67 (USB_DP)
/RP2354 Board/DP: R1.2, U1.66 (USB_DM)
/RP2354 Board/IO1: J6.10, U1.42 (GPIO33)
/RP2354 Board/PGD: R9.1, U1.58 (GPIO47/ADC7), U3.7 (PGOOD)
/RP2354 Board/RST: R4.2, U1.35 (RUN)
/RP2354 Board/SCLK: J1.2, U1.71 (QSPI_SCLK)
/RP2354 Board/SD0: J1.3, U1.72 (QSPI_SD0)
/RP2354 Board/SD1: J1.5, U1.74 (QSPI_SD1)
/RP2354 Board/SD2: J1.4, U1.73 (QSPI_SD2)
/RP2354 Board/SD3: J1.1, U1.70 (QSPI_SD3)
/RP2354 Board/SPI0_MISO: J6.7, U1.47 (GPIO38)
/RP2354 Board/SPI0_MOSI: J6.6, U1.48 (GPIO39)
/RP2354 Board/SPI1_MISO: J6.8, U1.46 (GPIO37)
/RP2354 Board/SPI1_MOSI: J6.9, U1.45 (GPIO36)
/RP2354 Board/SS: J1.6, U1.75 (~QSPI_SS)
/RP2354 Board/USBD+: J2.A6 (D+), J2.B6 (D+), U2.3 (I/O2)
/RP2354 Board/USBD-: J2.A7 (D-), J2.B7 (D-), U2.1 (I/O1)
/RP2354 Board/VBUCK: C4.1, C22.1, C24.1, R8.2, R9.2, U3.5 (EN2), U3.10 (OUT), U3.11 (OUT), U4.10 (VIN), U4.11 (VIN), U4.12 (VIN), U4.13 (EN)
/RP2354 Board/VBUS: C3.1, J2.A4 (VBUS), J2.A9 (VBUS), J2.B4 (VBUS), J2.B9 (VBUS), U2.5 (VBUS), U3.13 (IN)
/RP2354 Board/VOUT: J6.4, L2.1, R14.1, U4.1 (SW), U4.2 (SW), U4.3 (SW), U4.14 (VOS)
/RP2354 Board/VREGAVDD: C8.1, R6.2, U1.61 (VREG_AVDD)
/RP2354 Board/VREGlX: L1.2, U1.63 (VREG_LX)
/RP2354 Board/VSS: U3.8 (VSS), U3.17 (VSS)
/RP2354 Board/XIN: C1.1, U1.30 (XIN), Y1.1
/RP2354 Board/XOUT: C2.1, U1.31 (XOUT), Y1.3
GND: C1.2, C2.2, C3.2, C4.2, C5.2, C6.2, C7.2, C8.2, C9.2, C10.2, C11.2, C12.2, C13.2, C14.2, C18.2, C19.2, C20.2, C21.2, C22.2, C23.2, J2.A1 (GND), J2.A12 (GND), J2.B1 (GND), J2.B12 (GND), J2.SH (SHIELD), J3.2, R5.2, R7.2, R10.1, R11.1, R12.2, SW2.1, U1.62 (VREG_PGND), U1.81 (GND), U2.2 (GND), U3.1 (TS), U3.4 (CE), U3.6 (EN1), U3.14 (TMR), U3.15 (TD), U4.6 (GND), U4.7 (FSW), U4.8 (DEF), U4.15 (GND), U4.16 (GND), U4.17 (GND), Y1.2 (G), Y1.4 (G)
unnamed: J2.A5 (CC1), R7.1
unnamed: J2.B5 (CC2), R5.1
unnamed: C5.1, J3.1, U3.2 (BAT), U3.3 (BAT)
unnamed: J4.1, U1.40 (GPIO32)
unnamed: J4.2, U1.39 (GPIO31)
unnamed: J4.3, U1.38 (GPIO30)
unnamed: J4.4, U1.37 (GPIO29)
unnamed: J4.5, U1.36 (GPIO28)
unnamed: J4.6, U1.28 (GPIO27)
unnamed: J4.7, U1.27 (GPIO26)
unnamed: J4.8, U1.26 (GPIO25)
unnamed: J4.9, U1.25 (GPIO24)
unnamed: J4.10, U1.23 (GPIO23)
unnamed: J4.11, U1.22 (GPIO22)
unnamed: J4.12, U1.21 (GPIO21)
unnamed: J10.1, U1.12 (GPIO13)
unnamed: J10.2, U1.11 (GPIO12)
unnamed: J10.3, U1.9 (GPIO11)
unnamed: J10.4, U1.8 (GPIO10)
unnamed: J10.5, U1.7 (GPIO9)
unnamed: J10.6, U1.6 (GPIO8)
unnamed: J10.7, U1.4 (GPIO7)
unnamed: J10.8, U1.3 (GPIO6)
unnamed: J10.9, U1.2 (GPIO5)
unnamed: J10.10, U1.1 (GPIO4)
unnamed: R4.1, SW2.2
unnamed: R10.2, U3.12 (ILIM)
unnamed: R11.2, U3.16 (ISET)
unnamed: R12.1, R13.2, U4.5 (FB)
unnamed: R14.2, U4.4 (PG)
unnamed: C23.1, C24.2, U4.9 (SS/TR)

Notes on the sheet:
Voltage Regulator (Internal)
USB-C
Buck Converter
Crystal

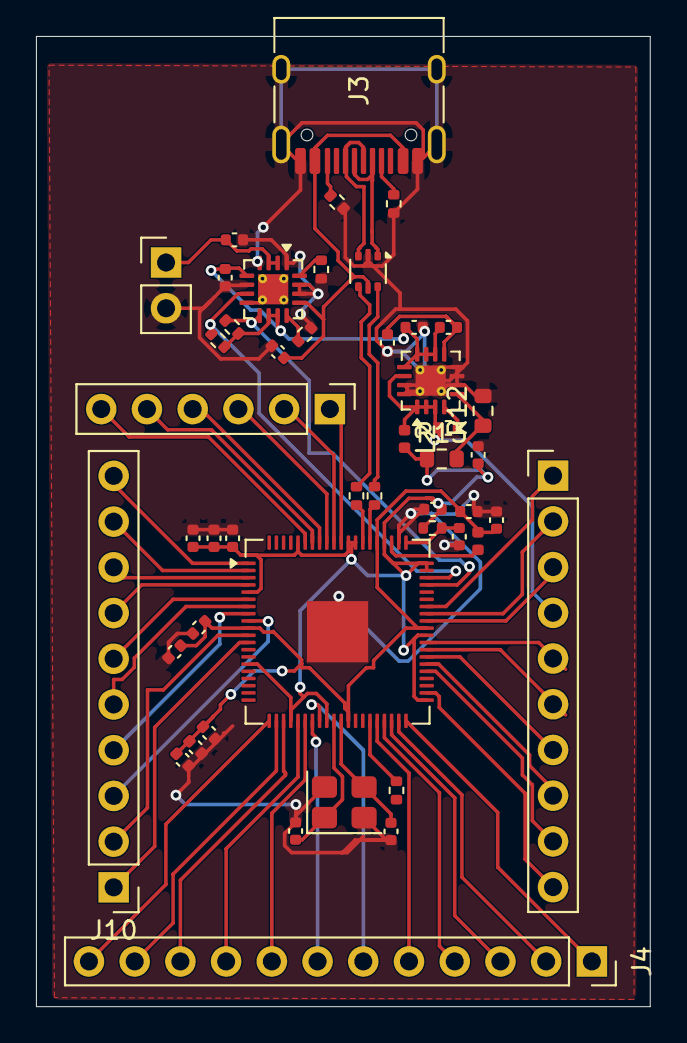
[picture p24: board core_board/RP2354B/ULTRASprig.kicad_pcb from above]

Board: 2 copper layers, 34.1 x 53.9 mm, 47 parts (0 on the bottom side), 65 nets.

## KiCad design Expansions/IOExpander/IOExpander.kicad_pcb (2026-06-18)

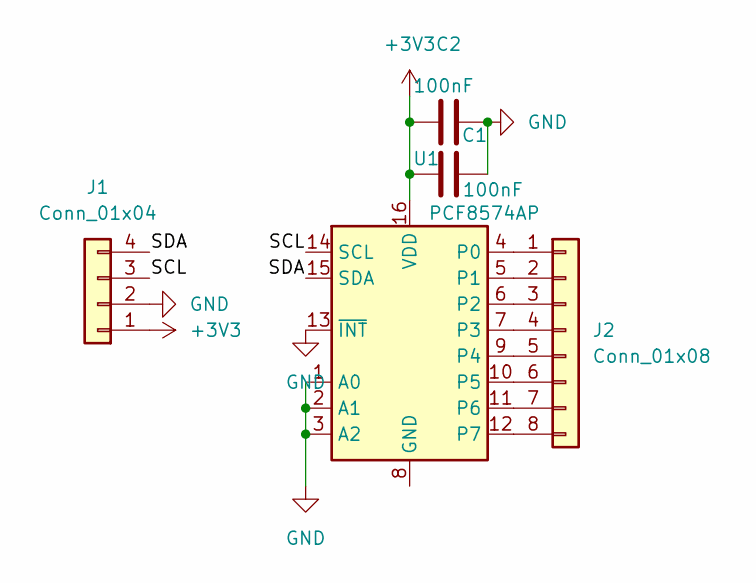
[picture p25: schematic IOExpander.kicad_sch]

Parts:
C1, C2: 100nF; C_0603_1608Metric
J1: Conn_01x04; PinHeader_1x04_P2.54mm_Horizontal
J2: Conn_01x08; PinHeader_1x09_P2.54mm_Horizontal
U1: PCF8574AP; DIP-16_W7.62mm

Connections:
+3V3: C1.2, C2.2, J1.1, U1.16 (VDD)
/SCL: J1.3, U1.14 (SCL)
/SDA: J1.4, U1.15 (SDA)
GND: C1.1, C2.1, J1.2, U1.1 (A0), U1.2 (A1), U1.3 (A2), U1.13 (~INT)
unnamed: J2.1, U1.4 (P0)
unnamed: J2.2, U1.5 (P1)
unnamed: J2.3, U1.6 (P2)
unnamed: J2.4, U1.7 (P3)
unnamed: J2.5, U1.9 (P4)
unnamed: J2.6, U1.10 (P5)
unnamed: J2.7, U1.11 (P6)
unnamed: J2.8, U1.12 (P7)

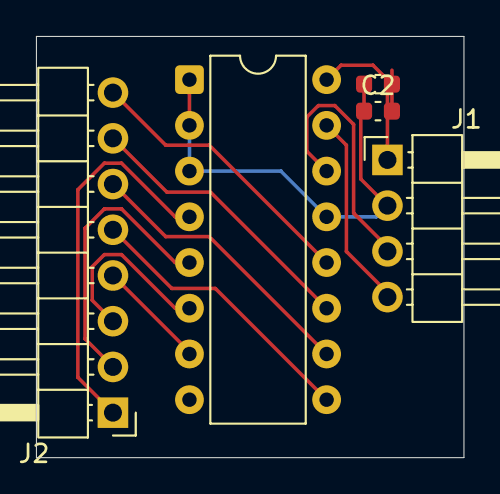
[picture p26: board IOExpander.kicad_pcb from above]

Board: 2 copper layers, 23.8 x 23.4 mm, 5 parts (0 on the bottom side), 12 nets.

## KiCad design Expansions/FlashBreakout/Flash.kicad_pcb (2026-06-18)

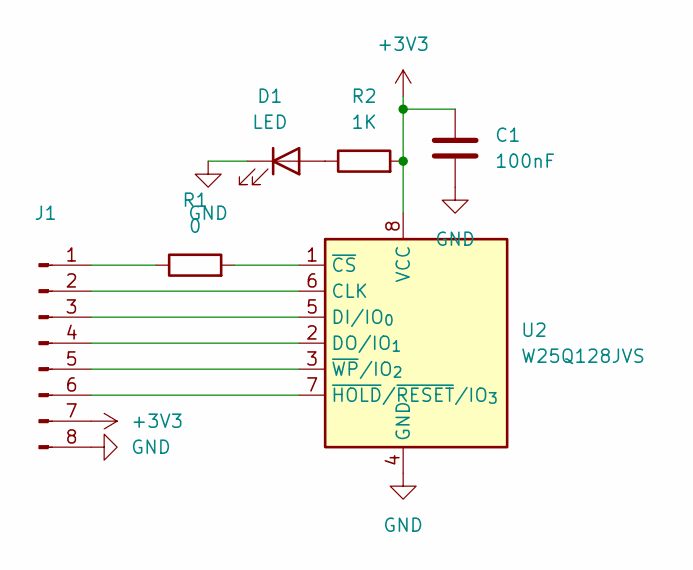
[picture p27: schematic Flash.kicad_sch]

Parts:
C1: 100nF; C_0402_1005Metric
D1: LED; LED_0603_1608Metric
J1: Conn_01x08_Pin; PinHeader_1x08_P2.54mm_Horizontal
R1: 0; R_0402_1005Metric
R2: 1K; R_0402_1005Metric
U2: W25Q128JVS; SOIC-8_5.3x5.3mm_P1.27mm

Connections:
+3V3: C1.1, J1.7, R2.2, U2.8 (VCC)
GND: C1.2, D1.1 (K), J1.8, U2.4 (GND)
unnamed: D1.2 (A), R2.1
unnamed: J1.1, R1.1
unnamed: J1.2, U2.6 (CLK)
unnamed: J1.3, U2.5 (DI/IO_{0})
unnamed: J1.4, U2.2 (DO/IO_{1})
unnamed: J1.5, U2.3 (~WP/IO_{2})
unnamed: J1.6, U2.7 (~HOLD/~RESET/IO_{3})
unnamed: R1.2, U2.1 (~CS)

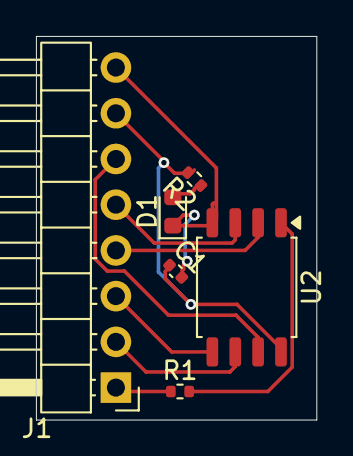
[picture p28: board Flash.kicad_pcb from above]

Board: 2 copper layers, 15.6 x 21.3 mm, 6 parts (0 on the bottom side), 10 nets.

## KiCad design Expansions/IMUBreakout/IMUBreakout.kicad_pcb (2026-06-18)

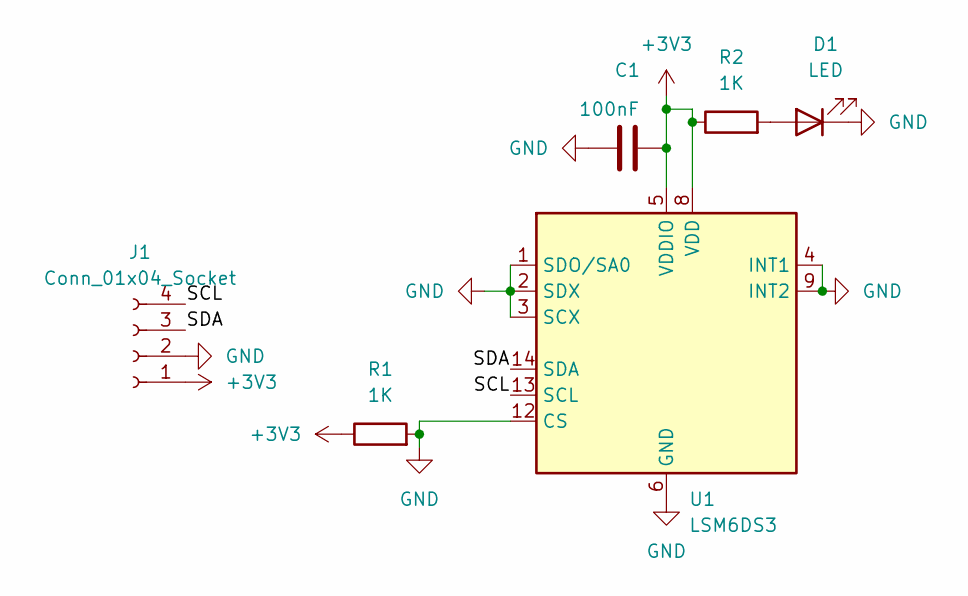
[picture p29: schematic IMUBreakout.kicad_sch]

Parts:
C1: 100nF; C_0402_1005Metric
D1: LED; LED_0603_1608Metric
J1: Conn_01x04_Socket; PinHeader_1x04_P2.54mm_Horizontal
R1, R2: 1K; R_0402_1005Metric
U1: LSM6DS3; LGA-14_3x2.5mm_P0.5mm_LayoutBorder3x4y

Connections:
+3V3: C1.1, J1.1, R1.1, R2.1, U1.5 (VDDIO), U1.8 (VDD)
/SCL: J1.4, U1.13 (SCL)
/SDA: J1.3, U1.14 (SDA)
GND: C1.2, D1.1 (K), J1.2, R1.2, U1.1 (SDO/SA0), U1.2 (SDX), U1.3 (SCX), U1.4 (INT1), U1.6 (GND), U1.7 (GND), U1.9 (INT2), U1.12 (CS)
unnamed: D1.2 (A), R2.2

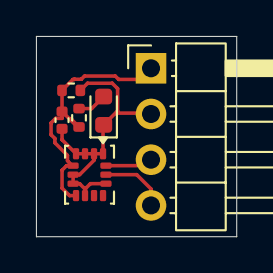
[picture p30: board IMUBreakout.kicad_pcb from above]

Board: 2 copper layers, 11.1 x 11.1 mm, 6 parts (0 on the bottom side), 5 nets.

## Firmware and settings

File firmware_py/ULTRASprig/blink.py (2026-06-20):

from machine import Pin
from utime import sleep
from machine import I2C, SDCard
import vfs
vfs.mount(SDCard(), "/sd")
pin = Pin("LED", Pin.OUT)
i2c0 = I2C(sda=22, scl=23, freq=40000)
i2c1 = I2C(sda=29, scl=30)
print("scanning bus 0 and 1")
b0 = i2c0.scan()
b1 = i2c1.scan() 
button_r1 = Pin(17, Pin.IN)
button_r2 = Pin(18, Pin.IN)
button_r3 = Pin(19, Pin.IN)
button_r4 = Pin(20, Pin.IN)
button_l1, button_l2, button_l3, button_l4 = Pin(3, Pin.IN), Pin(2, Pin.IN), Pin(28, Pin.IN), Pin(31, Pin.IN)
# for existing modules.
modules_addresses = [b'0x1C', '0x1B'] # lsm, pc
combined = b0 + b1
for i in modules_addresses:
    if combined.count(i) > 0:
        print("found {i}")
while True:
    if button_l1.value:
        print("left button one pressed")
    if button_l2.value:
        print("left button two pressed")
    if button_l3.value:
        print("left button three pressed")
    if button_l4.value:
        print("left button four pressed")
    if button_r1.value:
        print("right button one pressde")
    if button_r2.value:
        print("right button 2 pressde")
    if button_r3.value:
        print("right button 3 pressde")
    if button_r4.value:
        print("right button 4 pressde")
    vfs.

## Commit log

2026-06-16 add gerbers
    [BOM-ULTRASprig.csv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]
2026-06-16 remove extra files
    [RP2354B.kicad_pcb, RP2354B.kicad_sch, ULTRASprig.kicad_pcb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]
2026-06-18 add expansion modules
    [BOM-IOExpander.csv, BOM-ULTRASprig.csv, BOM.csv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]
2026-06-19 more stuff
    [BOM-IMUBreakout.csv, BOM-ULTRASprig.csv, BOM.csv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]
2026-06-19 add RP2354 BoM
    [BOM-ULTRASprig.csv, BOM.csv, RP2354B.kicad_sch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]
2026-06-19 add links, total price to BoM
    [BOM.csv]
2026-06-19 final readme
    [ULTRASprig.kicad_pcb]
2026-06-19 add zine, expand quick-links
    [BOM.csv, ULTRASprig.kicad_pcb]
2026-06-19 reformat, cleanup structure
    [Breakout.kicad_sch, ULTRASprig.kicad_pcb, ULTRASprig.kicad_sch]
2026-06-20 add firmware, CAD, buh
    [RP2354B.kicad_sch, ULTRASprig.kicad_sch]
2026-06-20 idk boss
    [BOM.csv]
2026-06-20 update stupid nbs
    [BOM.csv, ULTRASprig.kicad_pcb, ULTRASprig.kicad_sch]
